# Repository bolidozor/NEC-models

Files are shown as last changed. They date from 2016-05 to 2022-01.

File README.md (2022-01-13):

# NEC based antenna models
Models of Bolidozor antennas in NEC format.

Depends on NEC2++ python wrapper. It can be downloaded from: https://github.com/kaklik/python-necpp

## QFH Antenna OpenSCAD models

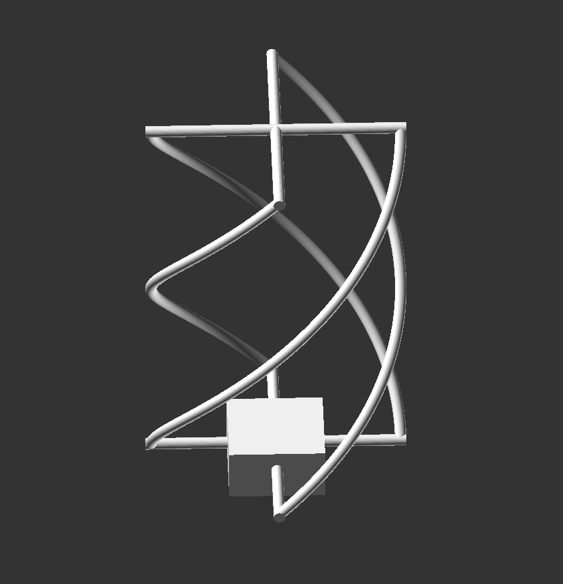
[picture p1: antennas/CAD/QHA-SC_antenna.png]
bolidozor QFH antenna array


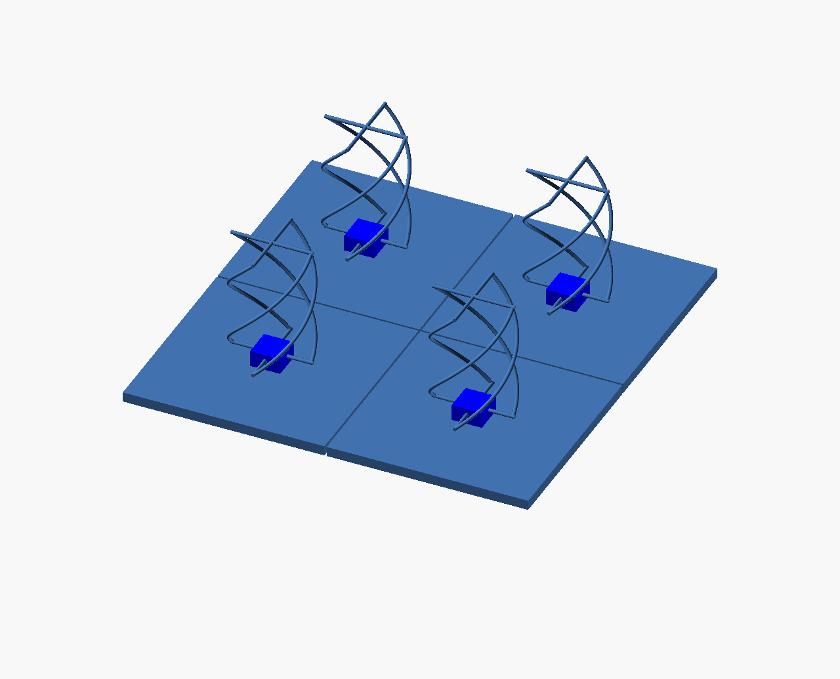
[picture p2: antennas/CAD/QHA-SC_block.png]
bolidozor QFH antenna array


## Simulation outputs

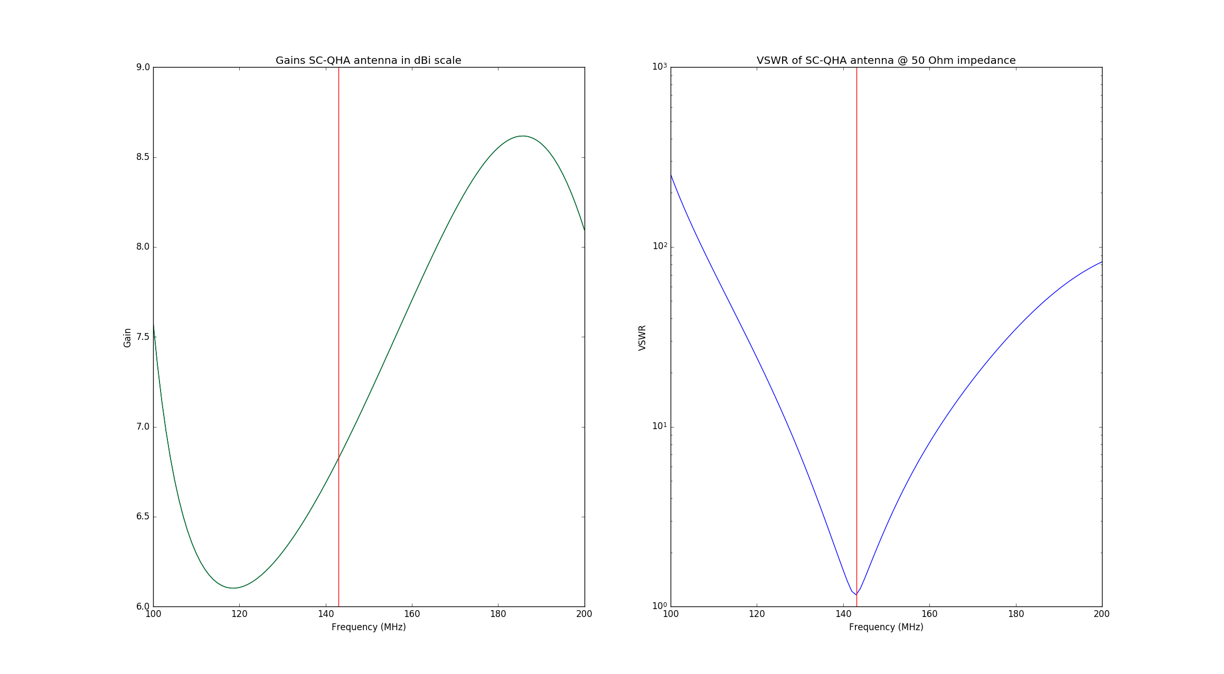
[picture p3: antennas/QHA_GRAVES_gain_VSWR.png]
bolidozor QFH antenna VSWR


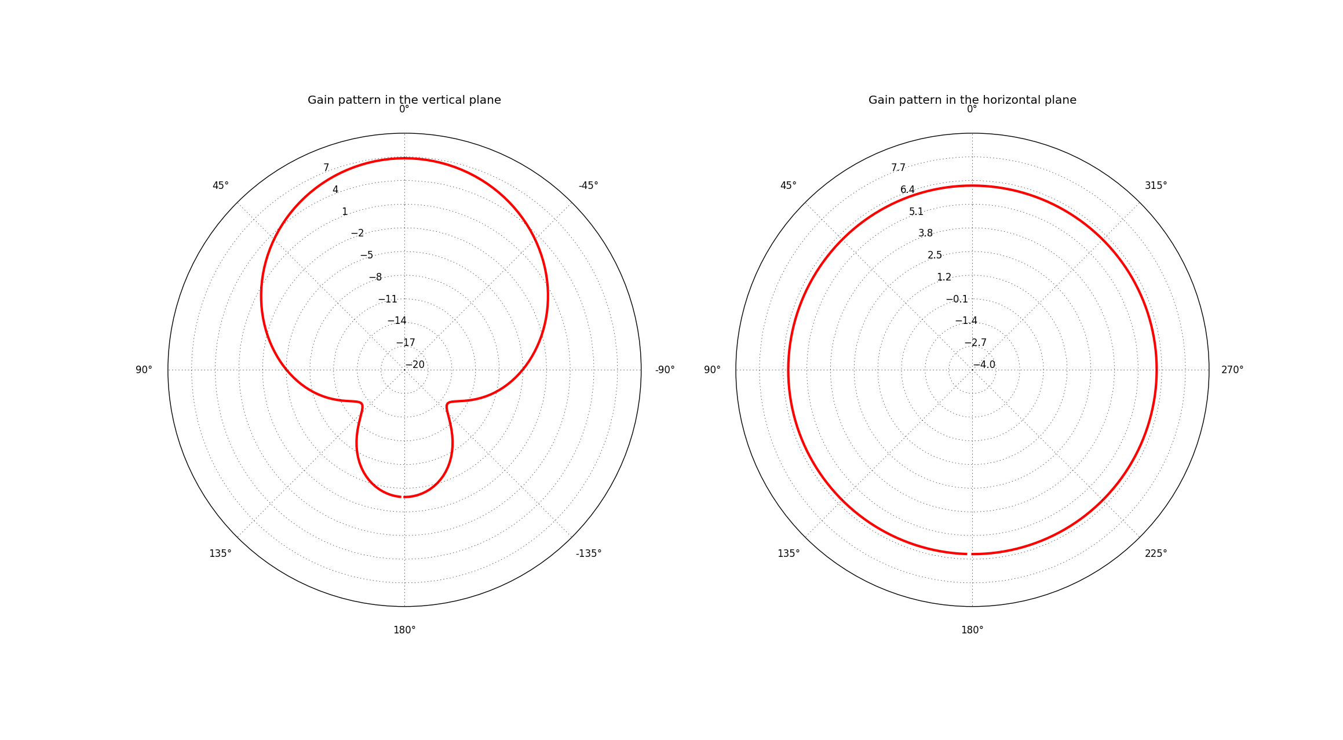
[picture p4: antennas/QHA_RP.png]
bolidozor QFH antenna radiation pattern


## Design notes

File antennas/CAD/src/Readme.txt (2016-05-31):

rezna delka uhelniku spodni zaklady: 

prumer + 2*13mm = 415,9 ~~ 416mm

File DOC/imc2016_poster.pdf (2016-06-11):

# Hemispherical radiating pattern antenna for radio meteor observation

Problem definition

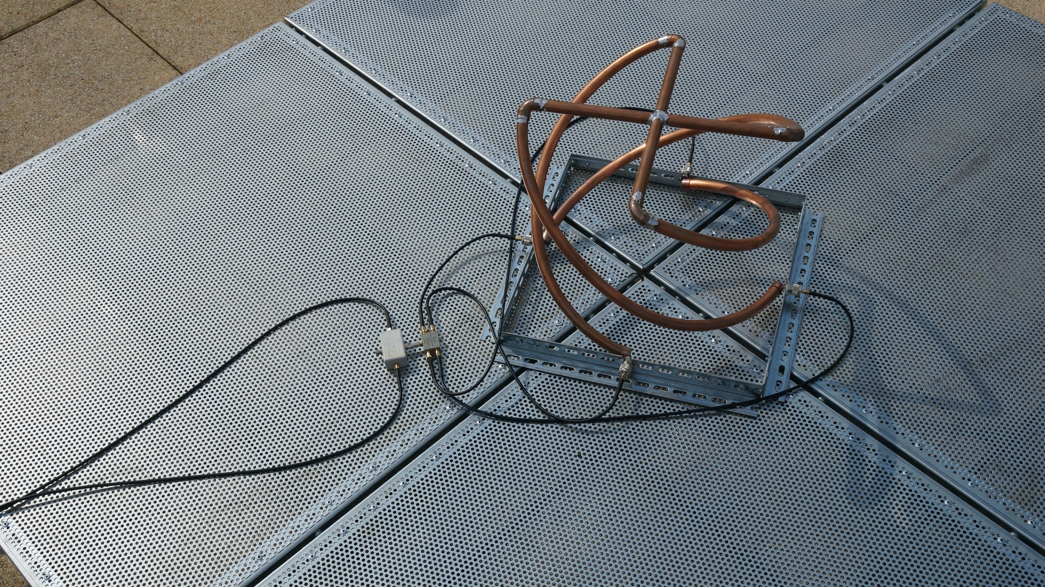
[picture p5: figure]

Historically, highly directional antenna designs such as Yagi were used for meteor observations. This approach was the simplest one due to the low sensitivity of receivers and easy mitigation of possible signal interference from other transmitters.

However, if we want to build a multistatic radar network, we need a different antenna design which meets the following requirements:

- All-sky sensitivity
- Stable parameters over hemisphere (polarization, gain)
- Attenuation of signals from very low elevations (terrestrial noise)
- Capability of antenna array construction
- Robust maintenance-free design.

Two types of airspace communication antennas were tested: a patch antenna designed from a wire-mesh and a short-circuited quadrifilar helix.

Figure 3 – Implemented form of patch antenna mounted on an observatory roof.

Bolidozor | Jakub Kákona¹ ²
| ¹ CTU Prague, Czech Republic, kakonjak@fel.cvut.cz, ² Universal Scientific Technologies s.r.o.

Patch antenna

QHA antenna

Conclusion

Both patch and QHA antennas were examined as potential candidates for multistatic observation networks. Unfortunately, the patch antenna was found too much manufacturing labor demanding and the antenna parameters were unstable therefore, it is insufficient for widespread use at Bolidozor stations. QHA antenna seems to be a better option but implemented prototype shows resonance almost 20 MHz above the designed frequency. The precise reason of this error must be further explored.

Figure 2 – Expected radiation pattern (vertical plane) of the patch antenna with a given size of reflector.

Figure 1 – Simplified drawing of a patch antenna design.

Figure 4 – Implemented form of quadrifilar helix mounted on a metal base.

Figure 5 – Expected radiation patterns of the quadrifilar helix antenna.

Figure 6 – Expected gain and impedance match of the quadrifilar helix antenna. Red vertical line indicates GRAVES radar carrier frequency.

Figure 7 – Measured reflection (impedance match) of the quadrifilar helix antenna.

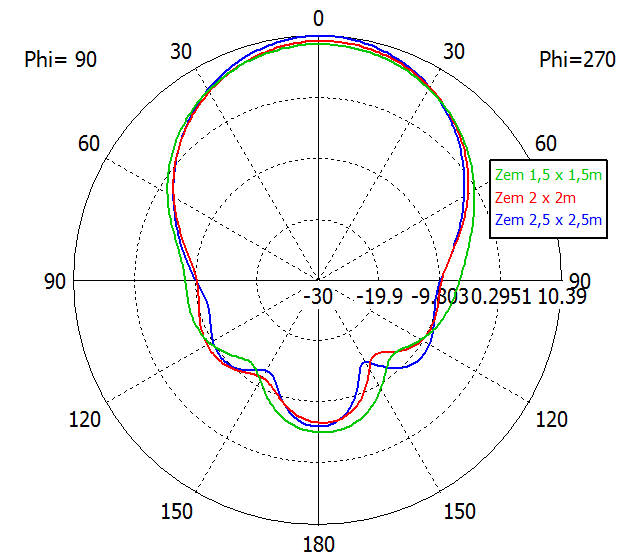
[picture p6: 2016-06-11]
DOC/src/img/patch_rp.png

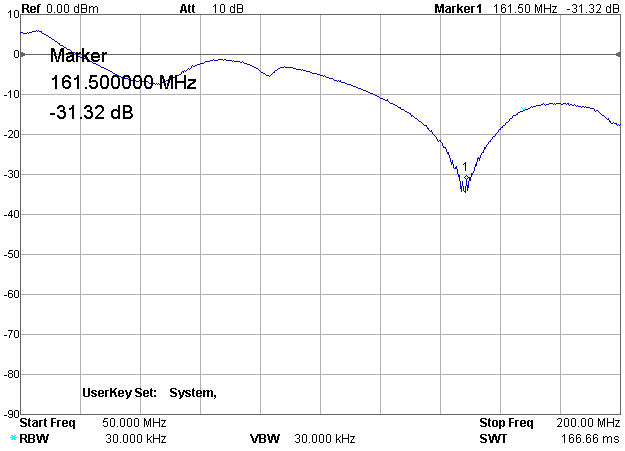
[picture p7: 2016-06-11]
DOC/src/img/sc-qha_prototype_resonance.png

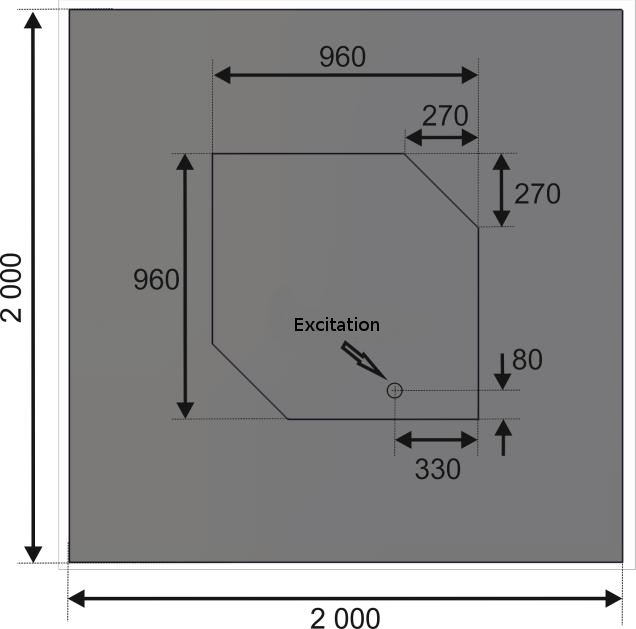
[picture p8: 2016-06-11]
DOC/src/img/patch_antenna_drawing.png

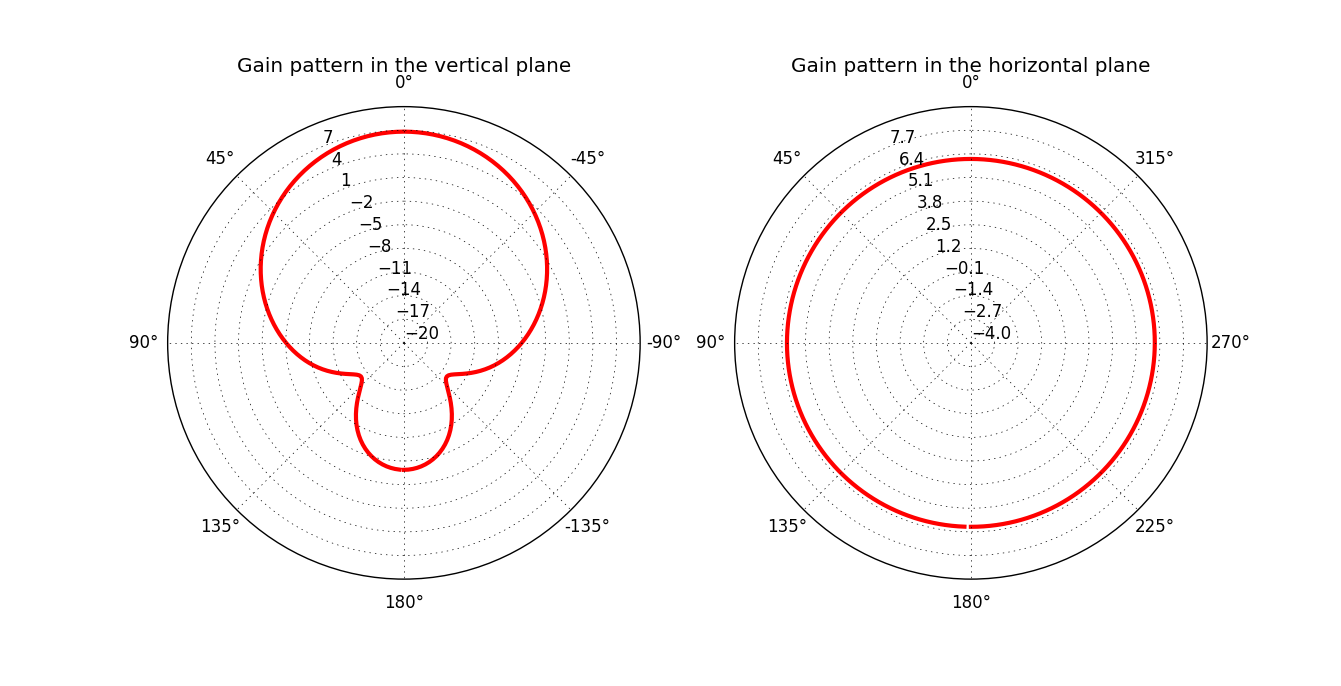
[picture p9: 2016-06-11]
DOC/src/img/qha_gains.png

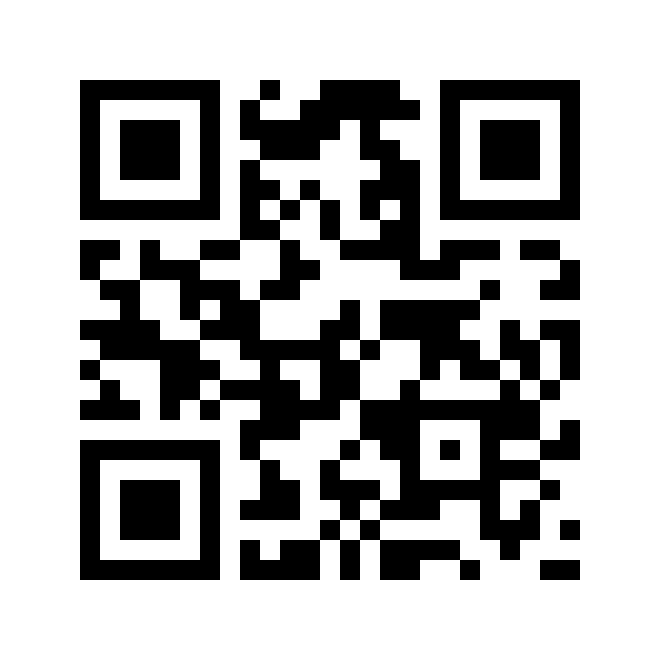
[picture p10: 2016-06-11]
DOC/src/img/QR_bolidozor_wiki.png

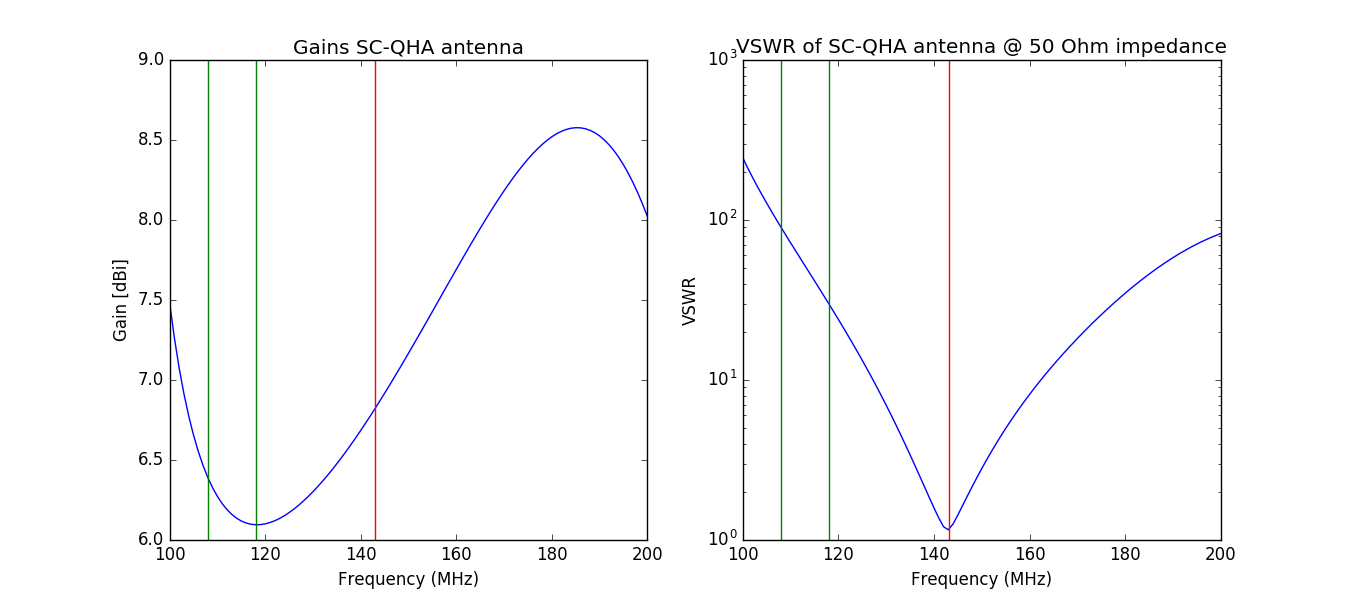
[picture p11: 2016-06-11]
DOC/src/img/qha_vswr.png

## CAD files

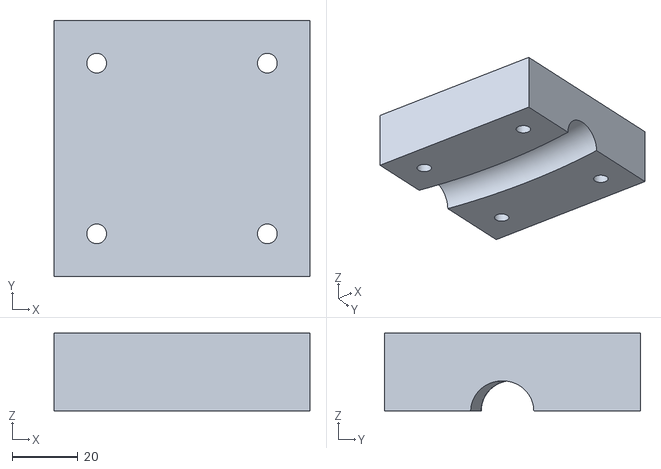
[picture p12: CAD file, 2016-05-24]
antennas/CAD/AMF/QHA-SC_bender_top.stl
78.0 x 78.0 x 23.8

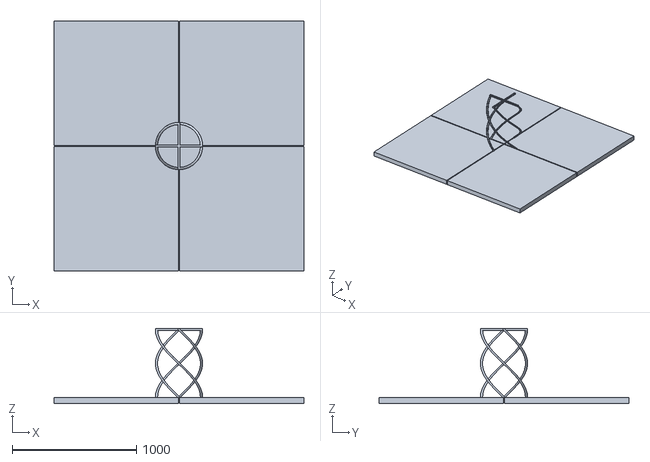
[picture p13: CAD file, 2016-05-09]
antennas/CAD/AMF/QHA-SC.stl
2010.0 x 2010.0 x 604.4

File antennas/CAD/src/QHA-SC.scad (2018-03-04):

// Bolidozor short-circuited QHA antenna

include <shortcuts.scad>  // http://www.thingiverse.com/thing:644830
$fn = 100;

wire_r = 18/2;
base_height = 50;
base_side = 2000;
base_margin = 10; 

height = 0.6*1000;
diameter = 0.3899*1000;

echo("Helix diameter:");
echo(diameter);
echo("Helix height");
echo(height);

echo("Helix cut tube lenght:");
helix_circumference = (diameter*PI);

helix_tube_lenght = sqrt(pow(helix_circumference/2,2) + pow(height,2));    // pythogarian calculation of helix_tube_lenght. 
echo(helix_tube_lenght ); //- wire_r

echo("Helix ascending angle:");
helix_angle = atan(height/(helix_circumference/2));
echo(helix_angle);

echo("Helix top tube cut lenght:");
echo(diameter - 2*wire_r -2); //


module elliptic_ring(r1 = 10, r2 = 5, r = 2, slices = 100, h = 0, w = 360)
{
  dz = h/slices; 
   dwx = atan(h/(r1+r2)/PI); 
  for (i = [0:slices-1])
  hull()
  {
    T(r1*cos((i+1)*w/slices), r2*sin((i+1)*w/slices), (i+1)*dz)
     R(90+dwx, 0, (i+1)*w/slices)
    Cy(r = r, h = .01); 
  
    T(r1*cos((i)*w/slices), r2*sin((i)*w/slices), i*dz)
     R(90+dwx, 0, i*w/slices)
    Cy(r = r, h = .01); 
  }
}


module loop() {
  union() {
    rotate([0,90,0])
        cylinder(r=wire_r, h=diameter + 2 * wire_r, center=true);
    translate([0,0,height]) 
        rotate([0,90,0]) 
            cylinder(r=wire_r, h=diameter + 2 * wire_r, center=true);  // top short circuiting conductor 
    
    elliptic_ring(h = height, w = 180, r1 = diameter/2, r2 = diameter/2, r = wire_r);  // half of helix loop
    rotate([0,0,180])
        elliptic_ring(h = height, w = 180, r1 = diameter/2, r2 = diameter/2, r = wire_r);  // second half of helix loop
  }
}

module quad_helix() {   
  union() {
    //z = (big_height - 0.238*lambda)/2;
    loop();
    rotate([0,0,90]) loop();
  }
}



module base() {
translate([base_margin/2, base_margin/2,0]) cube([base_side/2, base_side/2, base_height], center = false);
translate([-base_margin/2 - base_side/2, base_margin/2,0]) cube([base_side/2, base_side/2, base_height], center = false);
translate([-base_margin/2 - base_side/2,-base_margin/2 - base_side/2, 0]) cube([base_side/2, base_side/2, base_height], center = false);
translate([base_margin/2,-base_margin/2 - base_side/2, 0]) cube([base_side/2, base_side/2, base_height], center = false);
}

module antenna(){
  union() {
      translate([0,0,2*base_height]) 
        quad_helix();
      translate([0,0,base_height + 40])
        color("blue") cube([150, 150, 80], center = true);
//      base();
  }
}  

module antenna_block(){
    translate([base_side/4,base_side/4,0])
      union() {
          translate([0,0,2*base_height]) 
            quad_helix();
          translate([0,0,base_height + 40])
            color("blue") cube([150, 150, 80], center = true);
      }

    translate([-base_side/4,base_side/4,0])
      union() {
          translate([0,0,2*base_height]) 
            quad_helix();
          translate([0,0,base_height + 40])
            color("blue") cube([150, 150, 80], center = true);
      }

    translate([-base_side/4,-base_side/4,0])
      union() {
          translate([0,0,2*base_height]) 
            quad_helix();
          translate([0,0,base_height + 40])
            color("blue") cube([150, 150, 80], center = true);
      }

    translate([base_side/4,-base_side/4,0])
      union() {
          translate([0,0,2*base_height]) 
            quad_helix();
          translate([0,0,base_height + 40])
            color("blue") cube([150, 150, 80], center = true);
      }
  base();
}

module antenna_array(){
    translate([4000,0,0])
        antenna_block();

    translate([-4000,0,0])
        antenna_block();

    translate([0,4000,0])
        antenna_block();

    translate([0,-4000,0])
        antenna_block();

}


module manufacturing_helper(part = 1){
x_size = diameter/5;
y_size = diameter/5;

  difference() {
    translate([0, diameter/2, height/2])
      rotate([0, helix_angle, 0])
      {
        cube([x_size, y_size, wire_r*5], center = true);

      }
    loop();
    translate([0, diameter/2, height/2])
      rotate([0, helix_angle, 0])
      {
        if (part == 1)
          translate([0, 0, (wire_r*5)/2])        
            cube([diameter, diameter, wire_r*5], center = true);  // half cut
        else
          translate([0, 0, -(wire_r*5)/2])        
            cube([diameter, diameter, wire_r*5], center = true);  // half cut


        // mountig holes
        translate([x_size/3, y_size/3, 0])        
          cylinder(r=3, h=diameter, center=true);

        translate([x_size/3, -y_size/3, 0])        
          cylinder(r=3, h=diameter, center=true);

        translate([-x_size/3, -y_size/3, 0])        
          cylinder(r=3, h=diameter, center=true);

        translate([-x_size/3, y_size/3, 0])        
          cylinder(r=3, h=diameter, center=true);
      }
  }  
}

//manufacturing_helper(part = 1);
//antenna_array();
//antenna_block();
antenna();

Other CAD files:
antennas/CAD/AMF/QHA-SC_bender_bottom.stl
antennas/CAD/src/shortcuts.scad

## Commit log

2016-01-26 Current known antenna models added.
2016-05-09 New short circuited helical antenna openscad design added.
    [QHA-SC.scad, QHA-SC.stl]
2016-05-15 Top part helix wires splitted to four pieces to avoid intersection.
2016-05-15 A new antenna optimizer.
2016-05-18 Optimalization improved to match impedance 100 Ohm
2016-05-22 Antenna optimization improved.
2016-05-22 Fully working SC-QHA antenna optimizer.
2016-05-22 semi-working version of optimizer for QHA antenna with better geometry.
2016-05-23 attemp to model helix on perfect ground.
2016-05-23 VOR antenna optimization option added.
2016-05-23 antenna ploting changed to inline.
2016-05-23 manufacturing helix bending helper designed.
    [QHA-SC.scad, QHA-SC_bender_bottom.stl, QHA-SC_bender_top.stl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]
2016-05-24 bender components rotated to allows easier printing.
    [QHA-SC.scad, QHA-SC_bender_bottom.stl, QHA-SC_bender_top.stl]
2016-05-31 model improvements during antenna prototype construction.
    [QHA-SC.scad]
2017-09-18 Antenna design update.
    [QHA-SC.scad]
2017-09-19 Antenna array model created.
    [QHA-SC.scad]
2018-02-12 Antenna block and arrays rendered.
    [QHA-SC.scad]
2018-03-04 New siple antenna model rendered.
    [QHA-SC.scad]
